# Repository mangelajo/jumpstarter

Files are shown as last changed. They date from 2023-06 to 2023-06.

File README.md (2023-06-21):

# jumpstarter
jumpstarter is a project designed to enable generic Hardware in the Loop testability for Edge / embedded designs.

# Software Agent

Should enable standard CI tools and pipeline systems (tekton, gitlab, github, Jenkins, etc...) to integrate with the hardware:
 * Load a device image
 * Reboot
 * Gather logs and wait for finish
 * Return results to the CI system
 * Capture power profile during the whole device lifecycle.

# Hardware Agent
One of the components of the project is an Open Hardware board that bridges the Software and Hardware world
of Edge customers. Enabling them to perform Continous Integration of their Hardware and Software.

It's designed to be mounted on 1U 19" Server racks, in the MiniITX format, and should be connected to an
agent that will perform the control loop on the Device Under Test.

## Features

* USB Storage sharing
  * A storage device can be connected to the Testing host, and then passed down to the DUT
  * USB3.1 (up to 10Gbps) capable
  * USB3.0 and 2.0 capable for backwards compatibility
  * Storage device power cycling

* DUT Power management:
  * ON/OFF, Reset, Reboot
  * Measurement and logging in watts (Integration to Kepler)
  * 5-25V power supply support
  * USB-PD power supply support 5-20V with DUT power negotiation
 
* DUT Control (3.3v I/O)
  * UART Serial port TX/RX (for logging and tracing)
  * 4 customizable control signals
  * RESET signal

# Images of release 1.0.0, on prototyping stage

Yes, we are optimistic with versioning!

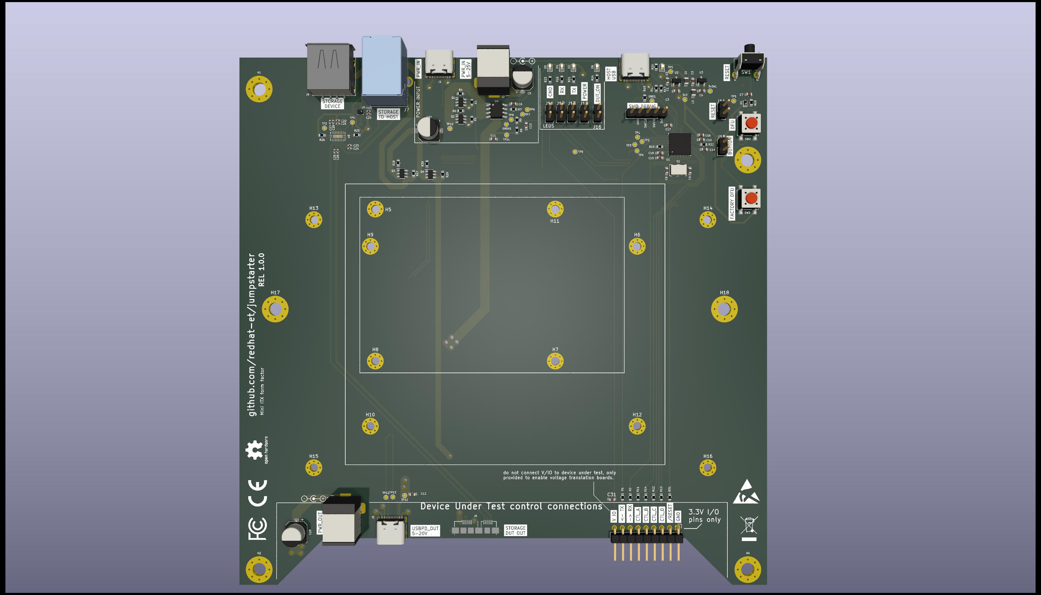
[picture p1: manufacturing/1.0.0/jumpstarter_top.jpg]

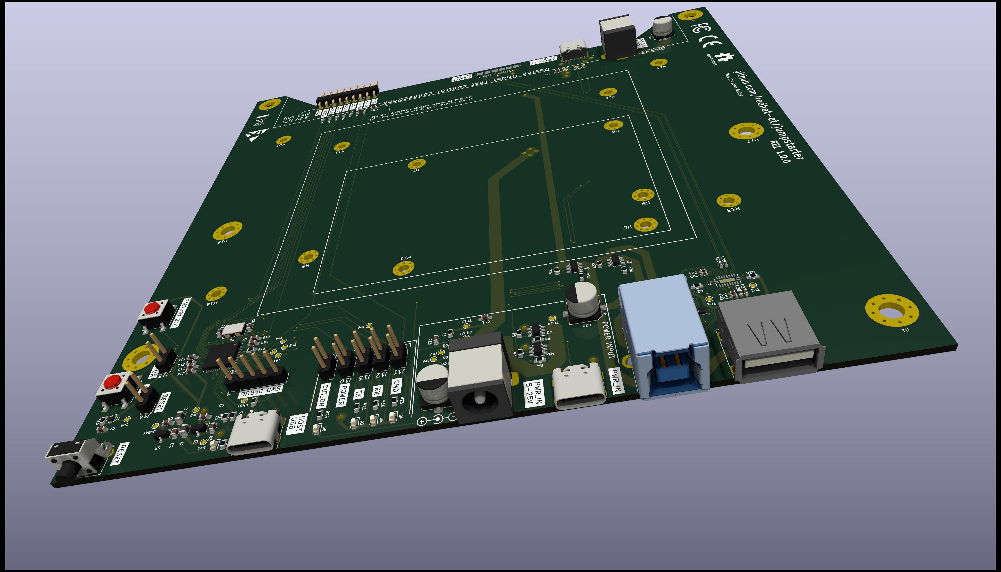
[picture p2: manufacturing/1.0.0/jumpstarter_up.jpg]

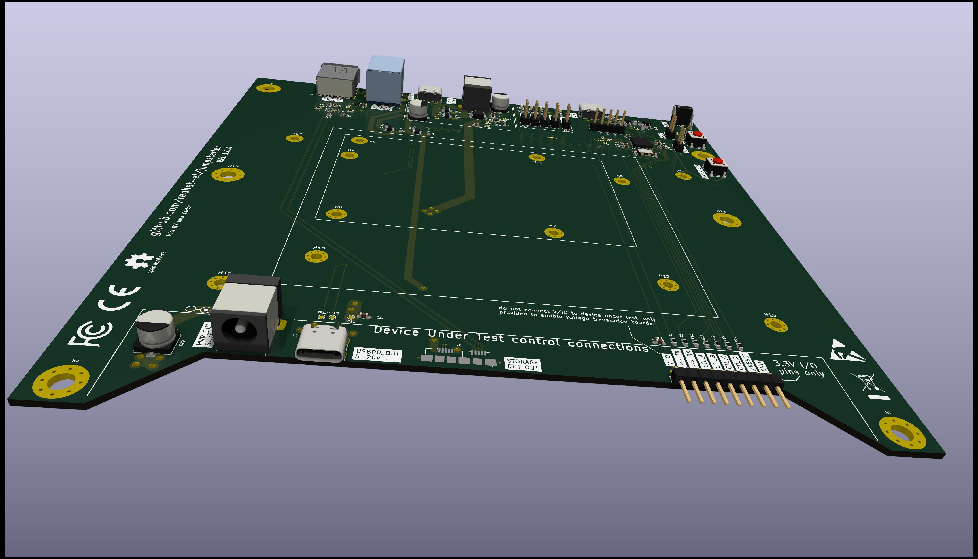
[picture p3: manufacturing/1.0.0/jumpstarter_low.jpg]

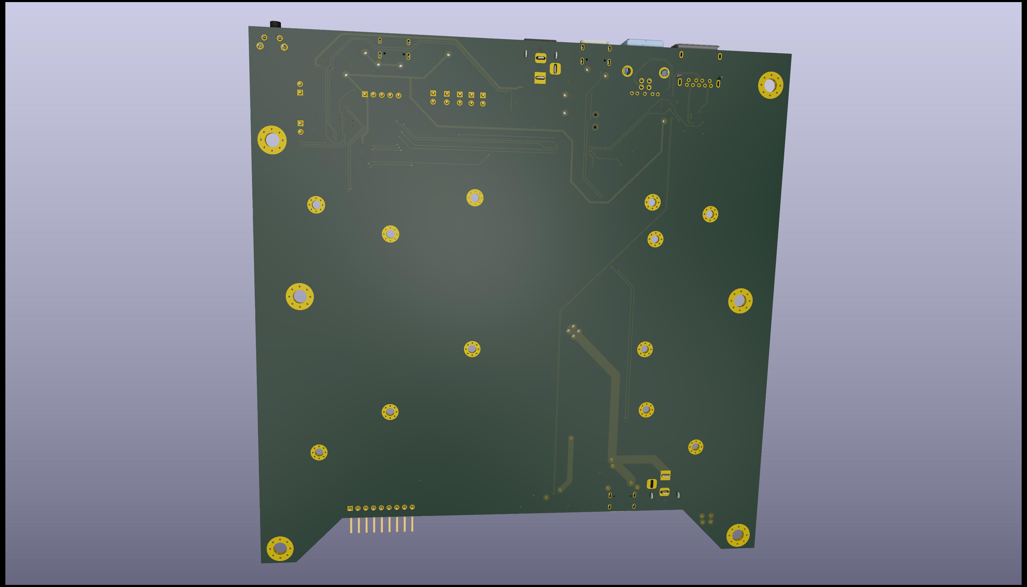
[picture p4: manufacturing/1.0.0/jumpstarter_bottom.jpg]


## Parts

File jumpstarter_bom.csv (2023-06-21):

Id | Designator | Footprint | Quantity | Designation | Supplier and ref
1 | C31,C3,C12,C1,C4,C11,C2,C6 | C_0603_1608Metric_Pad1.08x0.95mm_HandSolder | 8 | 1uF
2 | H2,H4,H3,H1 | MountingHole_4.3mm_M4_Pad_Via | 4 | ITX MountingHole
3 | C7,C16 | C_0603_1608Metric | 2 | 100nF
4 | R2,R1,R7 | R_0603_1608Metric | 3 | 50
5 | H10,H15,H16,H9,H12,H6,H13,H8,H7,H11,H14,H5 | MountingHole_2.7mm_M2.5_Pad_Via | 12 | Board MountingHole
6 | D5,D6,D3,D4,D2 | LED_0603_1608Metric | 5 | LED
7 | TP9,TP5,TP4,TP7,TP1,TP1,3v3,TP11,TP13,TP2,TP12,TP8,GND1,TP3,TP10,3v3A1,TP11,GNDA1,TP6,TP2,5V1 | TestPoint_Pad_D1.0mm | 21 | TestPoint
8 | R27,R3,R29,R5 | R_0603_1608Metric | 4 | 47k
9 | C10 | C_0603_1608Metric_Pad1.08x0.95mm_HandSolder | 1 | 2.2uF
10 | Q4,Q3,Q2,Q1 | TSOT-23-6 | 4 | FDC6330L
11 | H18,H17 | MountingHole_4.3mm_M4_Pad_Via | 2 | cable strap hole
12 | C27,C20,C25,C22,C28,C26,C23,C24 | C_0402_1005Metric | 8 | 100nF
13 | U3,U2 | SOT-23 | 2 | AP2127N-3.3
14 | J6 | PinHeader_1x05_P2.54mm_Vertical | 1 | Conn_01x05_Pin
15 | R13,R31,R12,R11,R14 | R_0603_1608Metric | 5 | 100
16 | C13,C14,C18,C15,C17 | C_0603_1608Metric_Pad1.08x0.95mm_HandSolder | 5 | 100nF
17 | J5,J1 | USB_C_Receptacle_G-Switch_GT-USB-7010ASV | 2 | USB_C_Receptacle_PowerOnly_6P
18 | R26,R25 | R_0603_1608Metric | 2 | 0
19 | J7 | Wurth WR-COM USB 3.0 692221030100 | 1 | USB3_B
20 | U1 | QFN-48-1EP_7x7mm_P0.5mm_EP5.6x5.6mm | 1 | STM32F411CEUx
21 | J12,J15,J11,J10,J13,J16,J14 | PinHeader_1x02_P2.54mm_Vertical | 7 | Conn_01x02_Pin
22 | R6,R4,R30,R28 | R_0603_1608Metric | 4 | 2k2
23 | J9 | USB3_A_Molex_48393-001 | 1 | USB3_A
24 | C8,C9 | C_0603_1608Metric_Pad1.08x0.95mm_HandSolder | 2 | 12pF
25 | SW3,SW2 | SW_SPST_B3S-1000 | 2 | SW_Push
26 | R15,R22 | R_0603_1608Metric | 2 | 10k
27 | J4 | PinHeader_1x09_P2.54mm_Horizontal | 1 | Conn_01x09_Pin
28 | R21,R23,R20,R16 | R_0603_1608Metric | 4 | 1k
29 | P1 | USB_C_Receptacle_G-Switch_GT-USB-7010ASV | 1 | USB_C_Plug_USB2.0
30 | U6 | DHVQFN-20-1EP_2.5x4.5mm_P0.5mm_EP1x3mm | 1 | TMUXHS4212
31 | L3,L1 | L_0805_2012Metric | 2 | 10uH
32 | C29,C5,C30 | CP_Elec_6.3x5.4_Nichicon | 3 | 47uF 32V
33 | Y2 | Oscillator_SMD_EuroQuartz_XO53-4Pin_5.0x3.2mm | 1 | 25 Mhz Crystal
34 | R24 | R_0603_1608Metric | 1 | 2k
35 | C21,C19 | C_0402_1005Metric | 2 | 1uF
36 | J3,J2 | BarrelJack_Horizontal | 2 | Barrel_Jack_MountingPin
37 | R8 | R_0603_1608Metric | 1 | 2k4
38 | R17,R18 | R_0603_1608Metric | 2 | 10
39 | R10 | R_0603_1608Metric | 1 | 4k7
40 | SW1 | SW_Tactile_SPST_Angled_PTS645Vx58-2LFS | 1 | SW_Push
41 | R9 | R_0603_1608Metric | 1 | 470
42 | U5 | UQFN-10_1.4x1.8mm_P0.4mm | 1 | ~
43 | U4 | SOIC-8_3.9x4.9mm_P1.27mm | 1 | ACS722LLCTR-10AU-T
44 | J8 | USB3_Micro-B_Connfly_DS1104-01 | 1 | USB3_B_Micro
45 | D1 | D_SOD-523 | 1 | 1N4148WT
46 | R19 | R_0603_1608Metric | 1 | 5k1

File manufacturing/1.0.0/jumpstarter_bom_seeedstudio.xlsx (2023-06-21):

Designator | Mfr Part / SKU | Qty | Link
C31,C3,C12,C1,C4,C11,C2,C6,C21,C19 | CL10B105KA8NNNC | 10 | 1uF 0603 capacitor
C7,C16,C27,C20,C25,C22,C28,C26,C23,C24,C13,C14,C18,C15,C17 | CL10B104KB8NNNC | 15 | 100nF 0603 capacitor
R2,R1,R7 | RC0402JR-0750RL | 3 | 50ohm 0603 resistor
D5,D6,D3,D4,D2 | LTST-C190KRKT | 5 | 0603 Red LED
R27,R3,R29,R5 | RC0603JR-0747KL | 4 | 47k 0603 resistor
C10 | CL10A225KP8NNNC | 1 | 2.2uF 0603 capacitor
Q4,Q3,Q2,Q1 | FDC6330L | 4 | https://www.mouser.es/ProductDetail/onsemi-Fairchild/FDC6330L?qs=efMQ9B2bthfkfJJoj5%252B07g%3D%3D
U3,U2 | AP2127N-3.3TRG1 | 2 | https://www.mouser.es/ProductDetail/Diodes-Incorporated/AP2127N-3.3TRG1?qs=x6A8l6qLYDCwIat%252BGHxAAg%3D%3D
J6 | B-2100S05P-A110 | 1 | 5 x 2.54mm male pin header straight
R13,R31,R12,R11,R14 | RTT031000FTP | 5 | 100 ohm 0603 resistor
J5,J1 | GT-USB-7010ASV | 2 | https://www.lcsc.com/product-detail/USB-Connectors_G-Switch-GT-USB-7010ASV_C2988369.html
R26,R25 | RC0603FR-070RL | 2 | 0 ohm 0603 resistor
J7 | 692221030100 | 1 | https://es.farnell.com/wurth-elektronik/692221030100/usb-3-0-tipo-b-hembra-th/dp/1861259?mckv=s_dc|pcrid|509002904386|kword|692221030100|match|p|plid||slid||product||pgrid|119454722043|ptaid|aud-1702385753400:kwd-25618251422|&CMP=KNC-GES-GEN-SKU-MDC-Connectors-Cable-Test-OOSandAudienceOpt-14-Feb-23
U1 | STM32F411CEU6 | 1
J12,J15,J11,J10,J13,J16,J14 | PZ254V-11-02P | 7 | 2 x 2.54mm male pin header straight
R6,R4,R30,R28 | RC0603FR-072K2L | 4 | 2k2 0603 resistor
J9 | 48393-0003 | 1 | https://es.farnell.com/molex/48393-0003/conector-usb-3-0-usb-tipo-a-hembra/dp/2401595?mckv=s_dc|pcrid|508918265685|kword|48393%200003|match|p|plid||slid||product||pgrid|121108853698|ptaid|aud-1702385753400:kwd-64953266167|&CMP=KNC-GES-GEN-SKU-MDC-Connectors-Cable-Test-OOSandAudienceOpt-14-Feb-23 (https://eu.mouser.com/ProductDetail/Molex/48393-0001?qs=4Ef8CTzXwRfUk7%252BJCOVflQ%3D%3D)
C8,C9 | CC0603JRNPO9BN120 | 2 | 12pF 0603 capacitor
SW3,SW2 | K2-1102SP-C4SC-04 | 2 | SMD SPST push button
R15,R22 | CRCW060310K0FKEA | 2 | 10k 0603 resistor
J4 | A2541WR-9P | 1 | 9 x 2.54mm male pin header 90 angle
R21,R23,R20,R16 | RTT031001FTP | 4 | 1k 0603 resistor
P1 | GT-USB-7010ASV | 1 | https://www.lcsc.com/product-detail/USB-Connectors_G-Switch-GT-USB-7010ASV_C2988369.html
U6 | TMUXHS4212RKSR | 1 | https://eu.mouser.com/ProductDetail/Texas-Instruments/TMUXHS4212RKSR?qs=7MVldsJ5UawhO1PzGdCV7Q%3D%3D
L3,L1 | MCL2012H100MT | 2 | 10uH 0805 Ferrite Bead 10µH ±20% 0805 0.85mm 2.00 x 1.25mm 500mΩ 100mA 20MHz
C29,C5,C30 | HV470M035E055ETR | 3 | 47uF 32V 6.3x5.4 SMD Electrolytic Capacitor
Y2 | SX32Y025000BG1T | 1 | 25 Mhz Crystal oscillator (Fusion Part)
R24 | RC0603FR-072KL | 1 | 2k 0603 resistor
J3,J2 | DC-005B-2.5A-2.5 | 2 | Barrel jack connector (Fusion part)
R8 | RC0603FR-072K4L | 1 | 2k4 0603
R17,R18 | RC0603JR-0710RL | 2 | 10 ohm 0603 resistor
R10 | RTT034701FTP | 1 | 4k7 0603 resistor
SW1 | K2-1102BQ-C4CW-01 | 1 | Button SPST angle, (Fusion part)
R9 | RC0603JR-07470RL | 1 | 470 ohm 0603 resistor
U5 | TMUXHS221NKGR | 1 | https://eu.mouser.com/ProductDetail/Texas-Instruments/TMUXHS221NKGR?qs=IPgv5n7u5QbuI%2Forjo3H9g%3D%3D (https://www.ti.com/product/TMUXHS221)
U4 | ACS725LLCTR-05AB-T | 1 | https://eu.mouser.com/ProductDetail/Allegro-MicroSystems/ACS725LLCTR-05AB-T?qs=pUKx8fyJudD0gM9RcXk04g%3D%3D
J8 | 692622030100 | 1 | https://eu.mouser.com/ProductDetail/Wurth-Elektronik/692622030100?qs=e5m3IbTHPW96DxjuTwzqKQ%3D%3D
D1 | 1N4148WT | 1 | https://eu.mouser.com/ProductDetail/onsemi-Fairchild/1N4148WT?qs=2%2FYqgE%252BHg%252BJTXBWnIBbu3Q%3D%3D
R19 | RC0603FR-075K1L | 1 | 5k1 0603 resistor

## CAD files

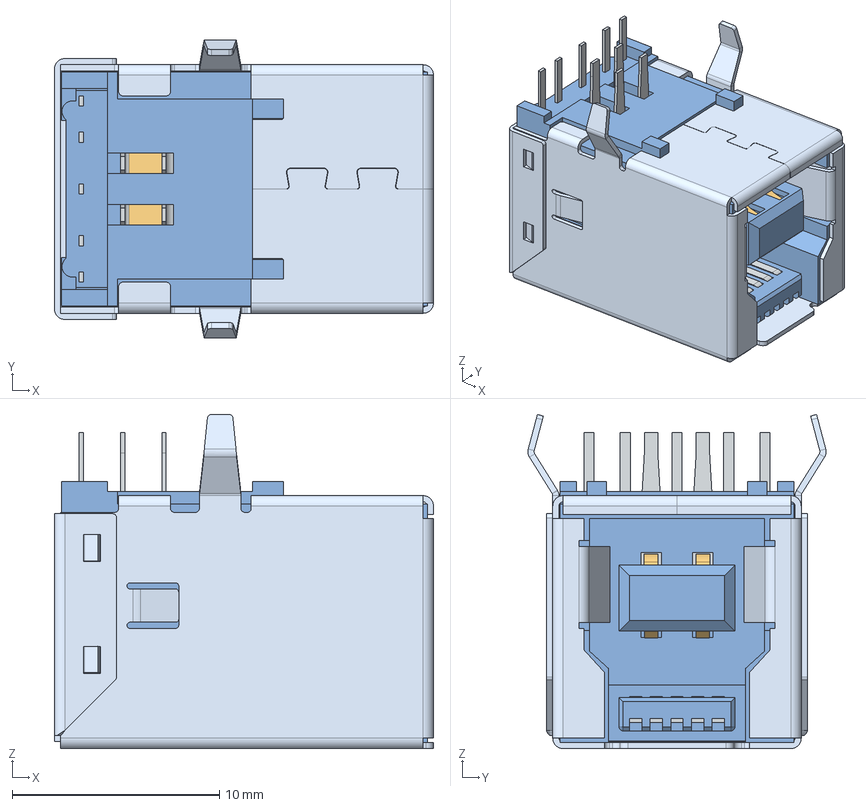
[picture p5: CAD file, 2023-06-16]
Download_STP_692221030100 (rev1).stp
18.3 x 14.4 x 16.1 mm
Housing1
Housing2
pin1 x 2
shielding
pin2 x 2
shielding_2
Housing3
pin3
pin4
pin5
pin3_mir2
pin4_mir2

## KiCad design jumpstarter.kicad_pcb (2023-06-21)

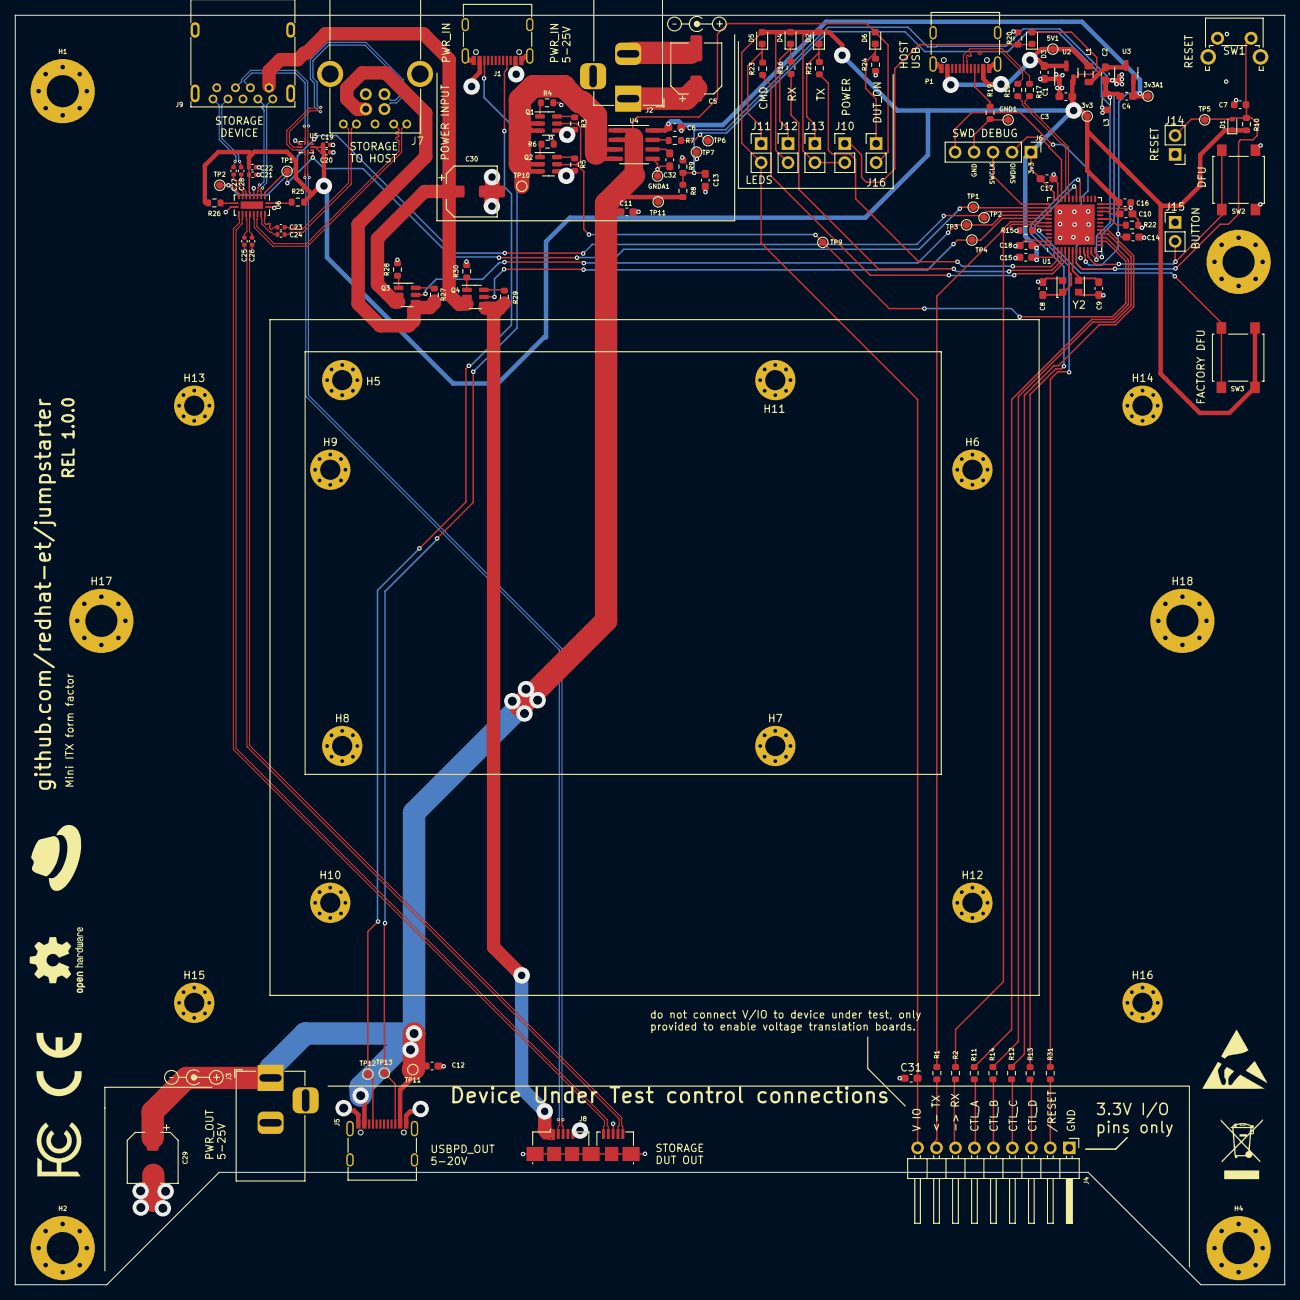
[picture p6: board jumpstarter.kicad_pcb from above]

Board: 4 copper layers, 170.0 x 170.0 mm, 140 parts (0 on the bottom side), 93 nets.

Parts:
3v3, 3v3A1, 5V1: TestPoint; TestPoint_Pad_D1.0mm
C1, C2, C3, C4, C6, C11, C12, C31: 1uF; C_0603_1608Metric_Pad1.08x0.95mm_HandSolder
C5, C29, C30: 47uF 32V; CP_Elec_6.3x5.4_Nichicon
C7, C16: 100nF; C_0603_1608Metric
C8, C9: 12pF; C_0603_1608Metric_Pad1.08x0.95mm_HandSolder
C10: 2.2uF; C_0603_1608Metric_Pad1.08x0.95mm_HandSolder
C13, C14, C15, C17, C18: 100nF; C_0603_1608Metric_Pad1.08x0.95mm_HandSolder
C19, C21: 1uF; C_0402_1005Metric
C20, C22, C23, C24, C25, C26, C27, C28: 100nF; C_0402_1005Metric
C32: 1nF; C_0603_1608Metric_Pad1.08x0.95mm_HandSolder
D1: 1N4148WT; D_SOD-523
D2, D3, D4, D5, D6: LED; LED_0603_1608Metric
GND1: TestPoint; TestPoint_Pad_D1.0mm
GNDA1: TestPoint; TestPoint_Pad_D1.0mm
H1, H2, H3, H4: ITX MountingHole; MountingHole_4.3mm_M4_Pad_Via
H5, H6, H7, H8, H9, H10, H11, H12, H13, H14, H15, H16: Board MountingHole; MountingHole_2.7mm_M2.5_Pad_Via
H17, H18: cable strap hole; MountingHole_4.3mm_M4_Pad_Via
J1, J5: USB_C_Receptacle_PowerOnly_6P; USB_C_Receptacle_G-Switch_GT-USB-7010ASV
J2, J3: Barrel_Jack_MountingPin; BarrelJack_Horizontal
J4: Conn_01x09_Pin; PinHeader_1x09_P2.54mm_Horizontal
J6: Conn_01x05_Pin; PinHeader_1x05_P2.54mm_Vertical
J7: USB3_B; Wurth WR-COM USB 3.0 692221030100
J8: USB3_B_Micro; USB3_Micro-B_Connfly_DS1104-01
J9: USB3_A; USB3_A_Molex_48393-001
J10, J11, J12, J13, J14, J15, J16: Conn_01x02_Pin; PinHeader_1x02_P2.54mm_Vertical
L1, L3: 10uH; L_0805_2012Metric
P1: USB_C_Plug_USB2.0; USB_C_Receptacle_G-Switch_GT-USB-7010ASV
Q1, Q2, Q3, Q4: FDC6330L; TSOT-23-6
R1, R2, R7: 50; R_0603_1608Metric
R3, R5, R27, R29: 47k; R_0603_1608Metric
R4, R6, R28, R30: 2k2; R_0603_1608Metric
R8: 2k4; R_0603_1608Metric
R9: 470; R_0603_1608Metric
R10: 4k7; R_0603_1608Metric
R11, R12, R13, R14, R31: 100; R_0603_1608Metric
R15, R22: 10k; R_0603_1608Metric
R16, R20, R21, R23: 1k; R_0603_1608Metric
R17, R18: 10; R_0603_1608Metric
R19: 5k1; R_0603_1608Metric
R24: 2k; R_0603_1608Metric
R25, R26: 0; R_0603_1608Metric
SW1: SW_Push; SW_Tactile_SPST_Angled_PTS645Vx58-2LFS
SW2, SW3: SW_Push; SW_SPST_B3S-1000
TP1, TP1#2, TP2, TP2#2, TP3, TP4, TP5, TP6, TP7, TP9, TP10, TP11, TP11#2, TP12, TP13: TestPoint; TestPoint_Pad_D1.0mm
U1: STM32F411CEUx; QFN-48-1EP_7x7mm_P0.5mm_EP5.6x5.6mm
U2, U3: AP2127N-3.3; SOT-23
U4: ACS725LLCTR-05AB-T; SOIC-8_3.9x4.9mm_P1.27mm
U5: UQFN-10_1.4x1.8mm_P0.4mm
U6: TMUXHS4212; DHVQFN-20-1EP_2.5x4.5mm_P0.5mm_EP1x3mm
Y2: 25 Mhz Crystal; Oscillator_SMD_EuroQuartz_XO32-4Pin_3.2x2.5mm

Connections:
+3.3V: 3v3.1, C3.1, C15.1, C16.1, C17.2, C18.1, C19.1, C20.1, C21.1, C22.1, C31.2, D1.1 (K), D2.2 (A), D3.2 (A), D4.2 (A), D5.2 (A), J4.9, J6.1, J10.2, J11.2, J12.2, J13.2, R10.2, R25.2, R26.2, SW3.2, U1.1 (VBAT), U1.24 (VDD), U1.36 (VDD), U1.48 (VDD), U2.2 (VO), U5.9 (3V3), U6.6 (VCC)
+3.3VA: 3v3A1.1, C4.2, C6.1, C14.1, U1.9 (VDDA), U3.2 (VO), U4.8 (VCC)
+5V: 5V1.1, C1.2, L1.2, P1.A4 (VBUS), P1.A9 (VBUS), P1.B4 (VBUS), P1.B9 (VBUS), U2.3 (VI)
+5VA: C2.2, L1.1, U3.3 (VI)
/BOOT0: R15.1, SW3.1, U1.44 (BOOT0)
/BUTTON: J15.2, SW2.1, U1.10 (PA0)
/CTL_A: R11.1, U1.15 (PA5)
/CTL_B: R14.1, U1.16 (PA6)
/CTL_C: R12.1, U1.17 (PA7)
/CTL_D: R13.1, U1.29 (PA8)
/CURRENT_SENSE: R7.2, TP6.1, U1.11 (PA1)
/DN: R17.1, U1.32 (PA11)
/DP: R18.1, U1.33 (PA12)
/LED0: R21.1, U1.2 (PC13)
/LED1: R16.1, U1.3 (PC14)
/LED2: R23.1, U1.4 (PC15)
/NRST: C7.2, D1.2 (A), J6.5, J14.2, R10.1, SW1.2, TP5.1, U1.7 (NRST)
/ON_OFF: Q1.5 (G1), Q2.5 (G1), TP9.1, U1.14 (PA4)
/RESET: R31.1, U1.30 (PA9)
/RX: J4.7, R2.1
/RX1: R2.2, U1.43 (PB7)
/SWCLK: J6.3, U1.37 (PA14)
/SWDIO: J6.2, U1.34 (PA13)
/TX: J4.8, R1.1
/TX1: R1.2, U1.42 (PB6)
/USB_OEn: TP1.1, TP1#2.1, U1.38 (PA15), U5.8 (OEn), U6.2 (OEn)
/USB_PW_DUT: Q4.5 (G1), TP4.1, U1.41 (PB5)
/USB_PW_HOST: Q3.5 (G1), TP3.1, U1.40 (PB4)
/USB_SEL: TP2.1, TP2#2.1, U1.39 (PB3), U5.10 (SEL), U6.9 (SEL)
/USB_STORAGE_MUX/DUT_DN: J8.2 (D-), U5.6 (DB-)
/USB_STORAGE_MUX/DUT_DP: J8.3 (D+), U5.7 (DB+)
/USB_STORAGE_MUX/DUT_SSRXN: C25.1, J8.9 (SSRX-)
/USB_STORAGE_MUX/DUT_SSRXP: C26.1, J8.10 (SSRX+)
/USB_STORAGE_MUX/DUT_SSTXN: J8.6 (SSTX-), U6.12 (C1n)
/USB_STORAGE_MUX/DUT_SSTXP: J8.7 (SSTX+), U6.13 (C1p)
/USB_STORAGE_MUX/HOST_DN: J7.2 (D-), U5.4 (DA-)
/USB_STORAGE_MUX/HOST_DP: J7.3 (D+), U5.5 (DA+)
/USB_STORAGE_MUX/HOST_SSRXN: C24.1, J7.8 (SSRX-)
/USB_STORAGE_MUX/HOST_SSRXP: C23.1, J7.9 (SSRX+)
/USB_STORAGE_MUX/HOST_SSTXN: J7.5 (SSTX-), U6.16 (B1n)
/USB_STORAGE_MUX/HOST_SSTXP: J7.6 (SSTX+), U6.17 (B1p)
/USB_STORAGE_MUX/STORAGE_DN: J9.2 (D-), U5.2 (D-)
/USB_STORAGE_MUX/STORAGE_DP: J9.3 (D+), U5.1 (D+)
/USB_STORAGE_MUX/STORAGE_SSRXN: C27.2, J9.5 (SSRX-)
/USB_STORAGE_MUX/STORAGE_SSRXP: C28.2, J9.6 (SSRX+)
/USB_STORAGE_MUX/STORAGE_SSTXN: J9.8 (SSTX-), U6.4 (A0n)
/USB_STORAGE_MUX/STORAGE_SSTXP: J9.9 (SSTX+), U6.3 (A0p)
/USB_STORAGE_MUX/VBUS_DUT: J8.1 (VBUS), Q4.4 (S2), R29.1
/USB_STORAGE_MUX/VBUS_HOST: J7.1 (VBUS), Q3.4 (S2), R27.1
/USB_STORAGE_MUX/VBUS_STORAGE: C30.1, J9.1 (VBUS), Q3.2 (D2), Q3.3 (D2), Q4.2 (D2), Q4.3 (D2)
/USB_STORAGE_MUX/_DUT_SSRXN: C25.2, U6.14 (C0n)
/USB_STORAGE_MUX/_DUT_SSRXP: C26.2, U6.15 (C0p)
/USB_STORAGE_MUX/_HOST_SSRXN: C24.2, U6.18 (B0n)
/USB_STORAGE_MUX/_HOST_SSRXP: C23.2, U6.19 (B0p)
/USB_STORAGE_MUX/_STORAGE_SSRXN: C27.1, U6.8 (A1n)
/USB_STORAGE_MUX/_STORAGE_SSRXP: C28.1, U6.7 (A1p)
/VOUT_SENSE: C13.1, R8.1, R9.2, TP7.1, U1.12 (PA2)
/XTALI: C9.2, U1.6 (PH1), Y2.3
/XTALO: C8.2, U1.5 (PH0), Y2.1
/_DN: P1.A7 (D-), R17.2
/_DP: P1.A6 (D+), R18.2
/board_control/CC1: J1.A5 (CC1), J5.A5 (CC1), TP12.1
/board_control/CC2: J1.B5 (CC2), J5.B5 (CC2), TP13.1
/board_control/CTL_A_: J4.6, R11.2
/board_control/CTL_B_: J4.5, R14.2
/board_control/CTL_C_: J4.4, R12.2
/board_control/CTL_D_: J4.3, R13.2
/board_control/RESET_: J4.2, R31.2
/board_control/VCCOUT: C11.1, C12.2, C29.1, D6.2 (A), J3.1, J5.A9 (VBUS), J5.B9 (VBUS), J16.2, R8.2, TP11.1, TP11#2.1, U4.1 (IP+), U4.2 (IP+)
/board_control/VCCOUT_SW: Q1.2 (D2), Q1.3 (D2), Q2.2 (D2), Q2.3 (D2), TP10.1, U4.3 (IP-), U4.4 (IP-)
/board_control/_CURRENT_SENSE: R7.1, U4.7 (VIOUT)
GND: C1.1, C3.2, C5.2, C7.1, C8.1, C9.1, C10.1, C11.2, C12.1, C13.2, C14.2, C15.2, C16.2, C17.1, C18.2, C19.2, C20.2, C21.2, C22.2, C29.2, C30.2, C31.1, GND1.1, H1.1, H2.1, H3.1, H4.1, H5.1, H6.1, H7.1, H8.1, H9.1, H10.1, H11.1, H12.1, H13.1, H14.1, H15.1, H16.1, H17.1, H18.1, J1.A12 (GND), J1.B12 (GND), J1.S1 (SHIELD), J2.2, J3.2, J4.1, J5.A12 (GND), J5.B12 (GND), J5.S1 (SHIELD), J6.4, J7.4 (GND), J7.7 (DRAIN), J7.10 (SHIELD), J8.5 (GND), J8.8 (DRAIN), J8.11 (SHIELD), J9.4 (GND), J9.7 (DRAIN), J9.10 (SHIELD), J14.1, J15.1, L3.2, P1.A1 (GND), P1.A12 (GND), P1.B1 (GND), P1.B12 (GND), P1.S1 (SHIELD), R4.2, R6.1, R15.2, R19.2, R20.1, R22.2, R24.1, R28.2, R30.2, SW1.1, SW2.2, U1.23 (VSS), U1.35 (VSS), U1.47 (VSS), U1.49 (VSS), U2.1 (GND), U5.3 (GND), U6.5 (GND), U6.11 (GND), U6.20 (GND), Y2.2, Y2.4
GNDA: C2.1, C4.1, C6.2, C32.2, GNDA1.1, L3.1, R9.1, U1.8 (VSSA), U3.1 (GND), U4.5 (GND)
unnamed: D2.1 (K), J13.1, R21.2
unnamed: D3.1 (K), J10.1, R20.2
unnamed: D4.1 (K), J12.1, R16.2
unnamed: D5.1 (K), J11.1, R23.2
unnamed: D6.1 (K), J16.1, R24.2
unnamed: P1.A5 (CC), R19.1
unnamed: Q1.6 (D1), R3.2
unnamed: Q1.1 (S1), R4.1
unnamed: Q2.6 (D1), R5.2
unnamed: Q2.1 (S1), R6.2
unnamed: Q3.6 (D1), R27.2
unnamed: Q3.1 (S1), R28.1
unnamed: Q4.6 (D1), R29.2
unnamed: Q4.1 (S1), R30.1
unnamed: R22.1, U1.20 (PB2)
unnamed: C10.2, U1.22 (VCAP1)
unnamed: C32.1, U4.6 (BW_SEL)
unnamed: R25.1, U6.1 (RSVD1)
unnamed: R26.1, U6.10 (RSVD2)
VCC: C5.1, J1.A9 (VBUS), J1.B9 (VBUS), J2.1, Q1.4 (S2), Q2.4 (S2), R3.1, R5.1

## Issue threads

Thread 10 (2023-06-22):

Move C5 further away from J2, they are too close

mangelajo, 2023-06-22:
This could be problematic if the capacitor is bigger than expected
or if we need to switch components.

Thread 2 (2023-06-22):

Add reverse polarity protection for the barrel jack power input

mangelajo, 2023-06-22:

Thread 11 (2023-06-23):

RFE: Autonomous support by having an on-board SOM (bottom layer)

mangelajo, 2023-06-23:
If there is a system-on-module we can support with RHEL4Edge, we could run the agent on board, avoiding the
need for a separate server host managing the DUT and the disk storage.

hgeaydem, 2023-06-23:
Wouldn't fedora-iot support be "good-enough" for that part ? (it does support rpi nano, which rhel won't ever do, and I don't know that we have any similarly specced SOM planned for support, with i.mx8m being the smallest supported ones I'm aware of so far and those being quite pricey for the purpose 😓
